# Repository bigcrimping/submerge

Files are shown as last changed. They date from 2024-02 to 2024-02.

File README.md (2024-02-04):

# submerge
IN-9 based wave meter running on ESP8266.

submerge

The ESP8266 connects to the API from Coastalmonitoring.org https://coastalmonitoring.org/ and pulls the latest wave height and wave period from the chosen buoy and converts it to a PWM signal to drive a IN-9 device

https://github.com/bigcrimping/submerge/assets/74270551/b3d905b5-1866-4489-b5fa-f626d71e5c9f

## Project Code

The code is here: https://github.com/bigcrimping/submerge/tree/main/code/bouy_code

You will need to add your WiFi details to the arduino_secrets.h as well as the key pair from https://coastalmonitoring.org/ccoresources/api/

Additionally you will need to install the following libraries: 

https://github.com/esp8266/Arduino/tree/master
https://arduinojson.org/

In the code you will find a routine "grab_data" which connects to the WiFi, connects to the API and requests the current wave height and period and returns it as floats. The API requires setting two custom HTTP headers

The display routing converts the wave period into a delay between each of the 84 samples in "wave_array[]" and scales it via the wave height.

The output full scale (PWM 255) is scaled to a max wave height of 6m which is a compromise between accuracy in extremely  high wave conditions and not looking boring at normal (0.8-1.2m) heights

The API requests the following attribution:

"Real time data displayed on this page are from the Regional Coastal Monitoring Programme, made freely available under the terms of the Open Government Licence. Please note that these are real-time data and are not quality-controlled."

## Wiring

I'm usually quite happy to share wiring diagrams, but this project contains 150V power supply which at best is extremely unpleasant to touch and at worst could cause serious injury.

If you want to copy this project, get someone who understands the risks to look over your circuit before powering it up.

For the PWM current drive I stole the design from https://www.limpkin.fr/index.php?post/2021/05/24/The-IN-9-Nixie-Clock

The power supply is a generic "DC5V-12V to 170V 150V-220V Glow Tube High Voltage Boost DC Power Module F/ Nixie" from the usual sort of vendors
You may need to burn your IN-9 tube in at higher current (20mA) for several hours to get the tube to light to the top.

## Mechanical Files



The design comprises (from top to bottom)  
Front
Spiral
base

When printing the spiral you will want to block supports inside the tube or you won't be able to get the wires to the IN-9 in

To attach the "front" to the "spiral" requires a 4.4mm diameter M2.5 insert, the base requires five 3.5mm diameter M2.5 inserts



STLs for printing available here: https://github.com/bigcrimping/submerge/tree/main/mech

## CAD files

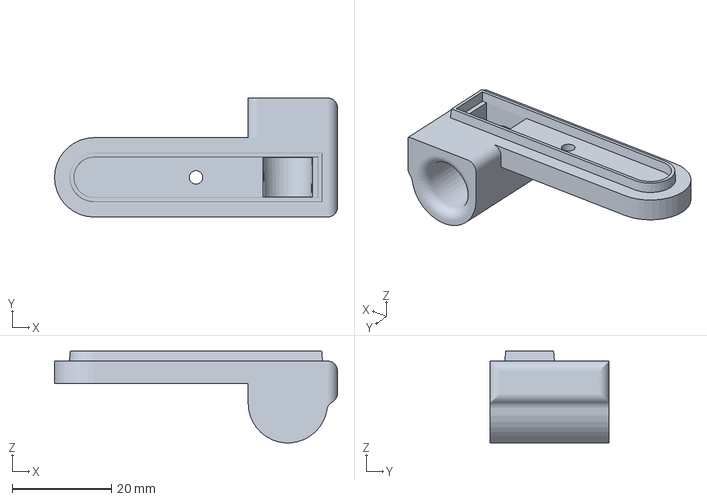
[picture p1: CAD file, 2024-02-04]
mech/front.3MF
57.0 x 24.0 x 18.5 mm

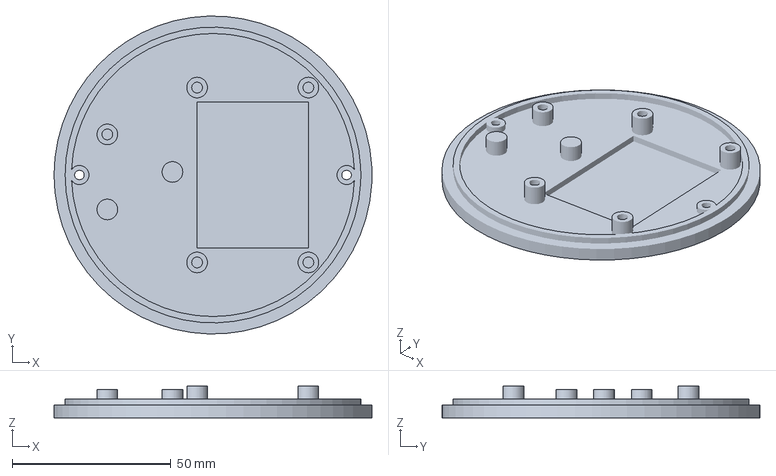
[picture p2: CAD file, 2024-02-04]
mech/base.3MF
100.0 x 100.0 x 10.0 mm

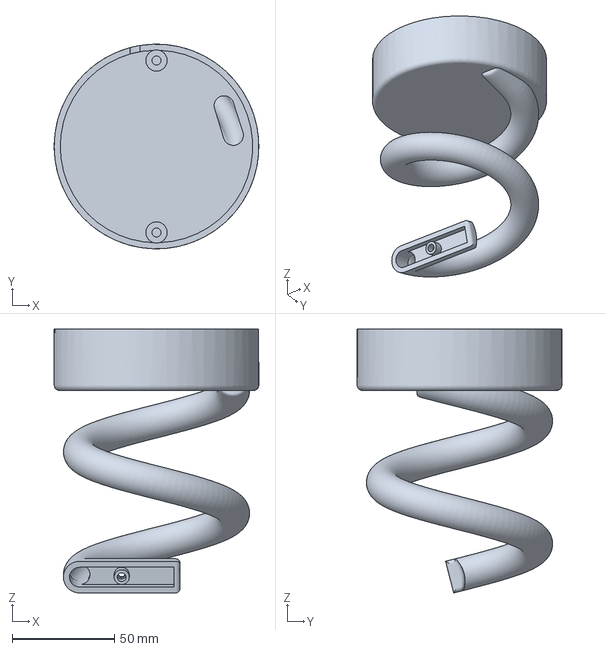
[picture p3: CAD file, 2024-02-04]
mech/spiral.3MF
100.0 x 100.0 x 129.0 mm

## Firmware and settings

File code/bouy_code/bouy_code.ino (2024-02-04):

#include <Arduino.h>
#include <ESP8266WiFiMulti.h>
#include <ESP8266HTTPClient.h>
#include <WiFiClientSecureBearSSL.h>
#include <ArduinoJson.h>
#include "wave_array.h"
#include "buoy_secrets.h"

ESP8266WiFiMulti WiFiMulti;
JsonDocument doc;

struct waveFloats_t {
 float hmax = 6.0;
 float tp = 10;
} wave_data;

const int nixiePin = 16;  //Output pin the IN-9 is controlled from

int loops = 100;

void setup() {
  pinMode(nixiePin,OUTPUT);
  analogWriteFreq(200);     //PWM frequency can be adapted to your tube
  Serial.begin(115200);
  WiFi.mode(WIFI_STA);
  WiFiMulti.addAP(SECRET_SSID, SECRET_PASS);
  delay(2000);
  
}

waveFloats_t grab_data (){
  waveFloats_t data_out;


    if ((WiFiMulti.run() == WL_CONNECTED)) {

    std::unique_ptr<BearSSL::WiFiClientSecure>client(new BearSSL::WiFiClientSecure);
    client->setInsecure();
    HTTPClient https;

    Serial.print("[HTTPS] begin...\n");
    if (https.begin(*client, "https://coastalmonitoring.org/observations/waves/latest.geojson?sensor=113&duration=0")) {  // the "sensor=13" defines the sensor, in this case St Mary's Sound 

      
      https.addHeader("Content-Type", "application/json"); 
      https.addHeader("X-API-Key", SECRET_KEY);
      https.addHeader("Referer", SECRET_REF);

      Serial.print("[HTTPS] GET...\n");
      int httpCode = https.GET();
      Serial.printf("Response code: %u\n",httpCode);
      Serial.printf("Content length: %u\n",https.getSize());
    
      if (httpCode > 0) {
        Serial.printf("[HTTPS] GET... code: %d\n", httpCode);

        if (httpCode == HTTP_CODE_OK || httpCode == HTTP_CODE_MOVED_PERMANENTLY) {
          String payload = https.getString();
          Serial.println(payload);

          DeserializationError error = deserializeJson(doc, payload);

          if (error) {
            Serial.print("deserializeJson() failed: ");
            Serial.println(error.c_str());
            data_out.hmax = 1.0;
            data_out.tp = 10;

            
          }

          const char* type = doc["type"];

          JsonObject features_0 = doc["features"][0];
          const char* features_0_type = features_0["type"]; 

          JsonObject features_0_properties = features_0["properties"];


          float hmax = features_0_properties["hmax"]; // Value for waveheight
          float tp = features_0_properties["tp"]; // Value for time period


          data_out.hmax = hmax;
          data_out.tp = tp;

        }
      } else {
        
        Serial.printf("[HTTPS] GET... failed, error: %s\n", https.errorToString(httpCode).c_str());
      }

      https.end();
    } else {
      Serial.printf("[HTTPS] Unable to connect\n");
    }

  }



  return data_out;
}

void loop() {
  
  waveFloats_t output_data= grab_data();
  float loop_delay = (output_data.tp / 84)*1000; //Convert wave period into 84 chunks of milliseconds

  while(1){
    if (loops = 0){
      waveFloats_t output_data= grab_data();
      
      loops = 100;
    }
    else{
      loops--;
    }
  

    Serial.print("Waveweight: ");
    Serial.println(float(output_data.hmax));
    Serial.print("Period: ");
    Serial.println(float(output_data.tp));
    
    float loop_delay = (output_data.tp / 84)*1000; //Convert wave period into 84 chunks of milliseconds

    
    for(int i = 0; i< 84; i++){
      float display_value = ((wave_array[i]*(output_data.hmax/2))+(output_data.hmax/2)); 
      //Serial.println(String(display_value));
      float intermediate = display_value * 43; //Max output is 255, scale the input max to be 6m/255 = 43 scaling factor
      analogWrite(nixiePin, int(intermediate));
      delay(loop_delay);
    }
  }
}
